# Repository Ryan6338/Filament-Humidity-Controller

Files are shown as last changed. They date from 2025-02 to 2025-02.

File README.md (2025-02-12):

# ESPHome Filament Humidity Controller (P/N 000001)
## Overview
This project is for an ESPHome-based 3D printer filament box. The purpose of the PCB is to automatically control a fan which will drive air through dessicant in a 3D printer filament drybox. Using ESPHome allows for easy configuration & automation customization through ESPHome and Home Assistant. It also allows for notifications to be configured when the dessicant has been depleted. The PCB is powered from a USB-C port requiring a 5V, 1A capable USB source. The USB port can be used for flashing the onboard ESP, although after ESPHome firmware has been installed, over the air updates can be used instead.

<p align="center">
  
</p>

## File Layout
### [KiCAD](KiCAD/)
The KiCAD folder contains the entire KiCAD project. This can be used to modify the board.
### [Manufacturing Documents](Manufacturing%20Documents/)
The manufacturing documents contains all output files of the KiCAD project. These files fully define the finished PCB. The main document is 000001.pdf. This file has notes defining the other files.
### [Calculations](Calculations/)
Calculations & design criteria can be found in the calculations folder. SMath (.sm) files are used to generate the output files in this folder (.pdf).
### [Simulations](Simulations/)
The simulations folder contains LTSpice simulations generated during the project.
## Board Architecture
A block diagram of the board architecture is pictured below. Each block in the diagram is described in this section.

Humidity Controller Block Diagram

### USB-C Connector
The board takes in power from the USB-C connector and runs it to both a 12V boost converter and 3.3V linear regulator. The CC pins are used by the upstream device to communicate how much power can be supplied.
### 12V Boost Converter
The 12V boost converter receives 5V (4.75-5.25V) from the USB-C connector & converts it into 12V for the fan. The boost converter is only active when the enable signal is triggered by the ESP32.
### 3.3V Linear Regulator
The 3.3V linear regulator receives 5V from the USB-C connector and regulates it to 3.3V for the humidity sensor & ESP32.
### Humidity Sensor
The humidity sensor receives 3.3V from the linear regulator & is an I2C slave device on the I2C bus connected to the ESP32.
### ESP32
The ESP32 runs ESPHome firmware with a driver to perform fan control with speed feedback & to receive humidity sensor data. Using the custom humidity sensor & fan drivers, the firmware for the ESP32 can be generated using a standard ESPHome yaml file. The ESP32 interfaces with an ESPHome server allowing for easy configuration of control parameters. Upon power on, the ESP32 reads the voltage of the CC pins to ensure adequate power is available from the USB supply prior to enabling the boost converter.
### Fan Connector
The fan connector is a standard 4-Pin computer fan connector which can be used with any 12V computer fan which has a maximum current draw of 200mA or less.
## TODO
1. Write custom ESPHome driver.
2. Create example yaml for ESPHome using custom driver.
3. Design PCB bracket, fan housing & dessicant holder.
## Future Improvements
To make this product consumer-ready, the following improvements should be considered:
1. Add fuse to 5V input.
2. Add ESD protection on USB & fan connectors.

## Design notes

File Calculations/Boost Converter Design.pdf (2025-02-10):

## Non-synchronous Boost Converter Calculations

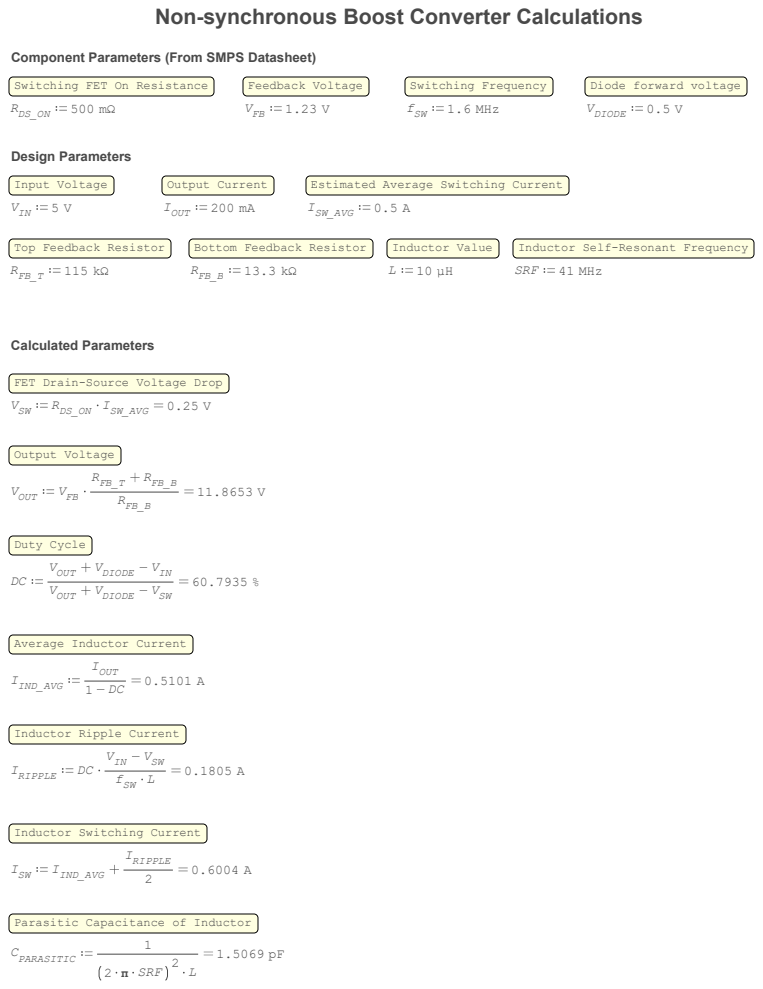
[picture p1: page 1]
Feedback Voltage; Switching Frequency; MHz1.6 SW; 0.5 V DIODE; Design Parameters; Input Voltage; Output Current; mA200 OUT; 0.5 A SW_AVG; Inductor Value; SRF; MHz41; Calculated Parameters; 0.25 V SW_AVG RDS_ON VSW; Output Voltage; RFB_B; RFB_B RFB_T VFB VOUT; IOUT; IIND_AVG; 0.1805 A LfSW; VSW VIN I; DC RIPPLE; 2 π SRF

Component Parameters (From SMPS Datasheet)

Switching FET On Resistance

Diode forward voltage

Estimated Average Switching Current

Top Feedback Resistor

Bottom Feedback Resistor

Inductor Self-Resonant Frequency

FET Drain-Source Voltage Drop

Duty Cycle
VIN VDIODE VOUT

VSW VDIODE VOUT

Average Inductor Current

Inductor Ripple Current

Inductor Switching Current
IRIPPLE IIND_AVG ISW

Parasitic Capacitance of Inductor
1 CPARASITIC

## Output Filter Design

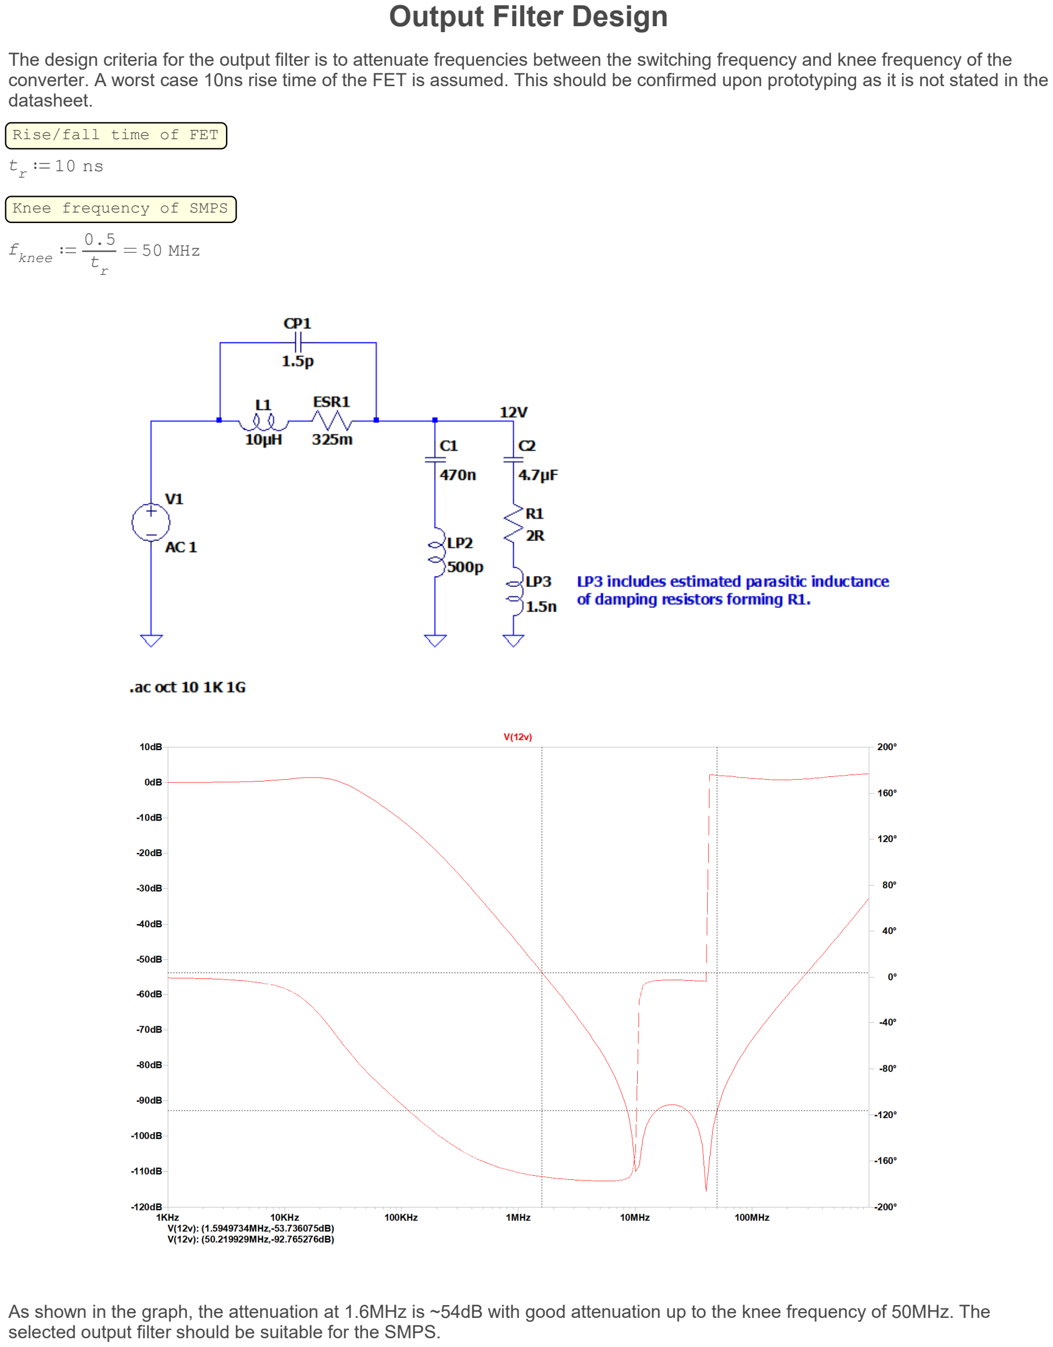
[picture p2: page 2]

The design criteria for the output filter is to attenuate frequencies between the switching frequency and knee frequency of the converter. A worst case 10ns rise time of the FET is assumed. This should be confirmed upon prototyping as it is not stated in the datasheet.

Rise/fall time of FET
t | ns10 r

Knee frequency of SMPS

MHz50
tr

0.5 fknee

As shown in the graph, the attenuation at 1.6MHz is ~54dB with good attenuation up to the knee frequency of 50MHz. The selected output filter should be suitable for the SMPS.

## Transient Analysis

A transient analysis was performed to check the circuit performs as expected. The fixed duty cycle calculated in the SMPS calcs. This simulation does not include the control loop of the SMPS. It is assumed to be stable as the loop compensation recommendations in the datasheet have been followed.

Parameters found by simulation:
Avg Inductor Current (L1): 570mA
Peak Inductor Current (L1): 650mA
Output Ripple Voltage: 250μA
Avg Power of ESR2: 2.3mW

The inductor current was found to be slightly higher during the simulation, this is mostly due to the inclusion of ESR in the simulated inductor. Otherwise, the calculated duty cycle matched the simulation results, a 60.79% duty cycle resulted in an output voltage (BST_12V) of 11.86V. As shown in the graph, the output filter is effective at attenuating the switching noise.

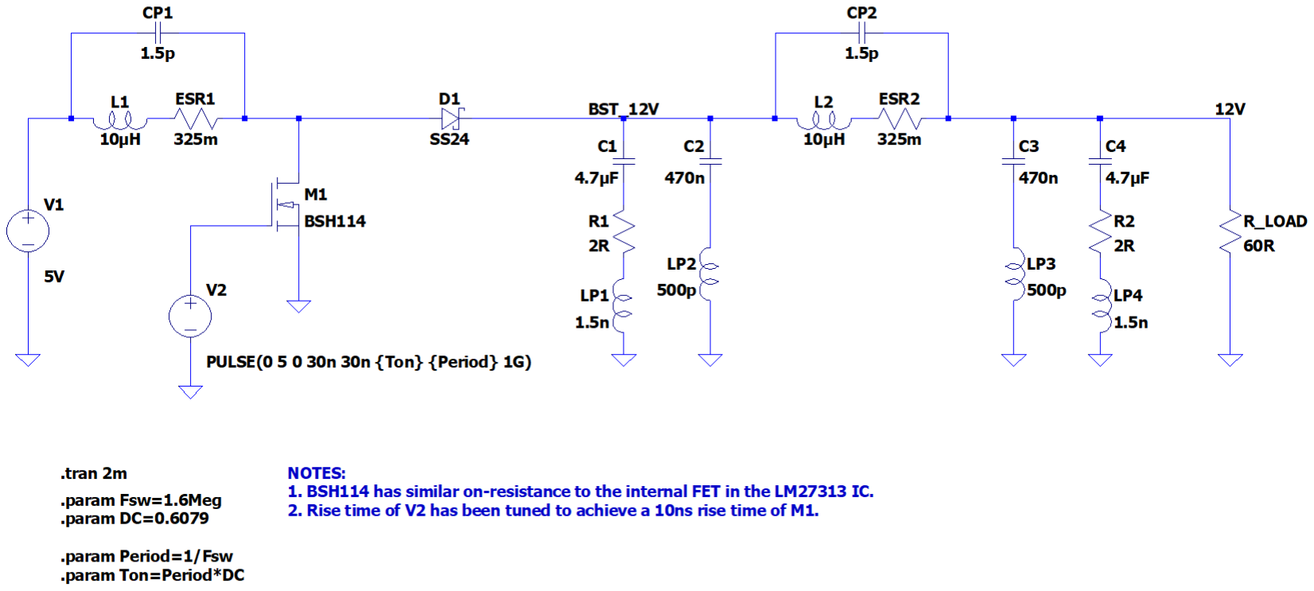
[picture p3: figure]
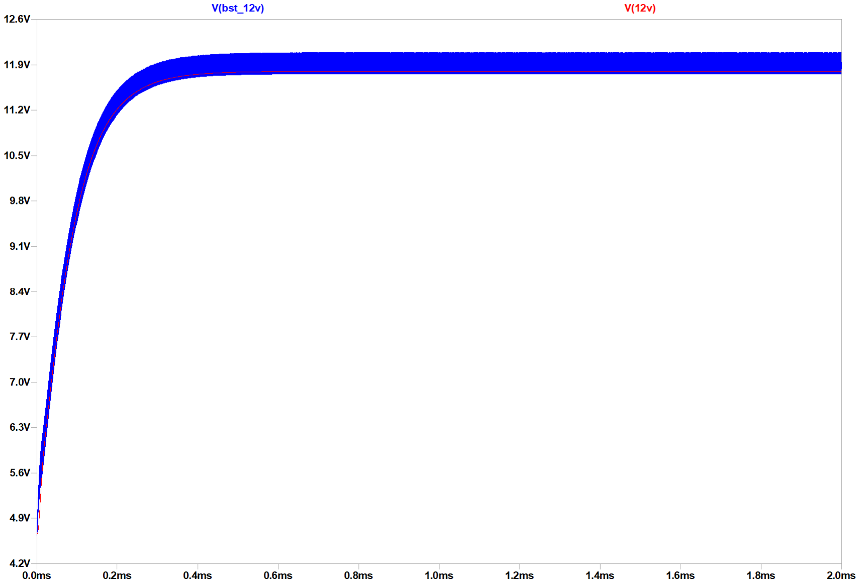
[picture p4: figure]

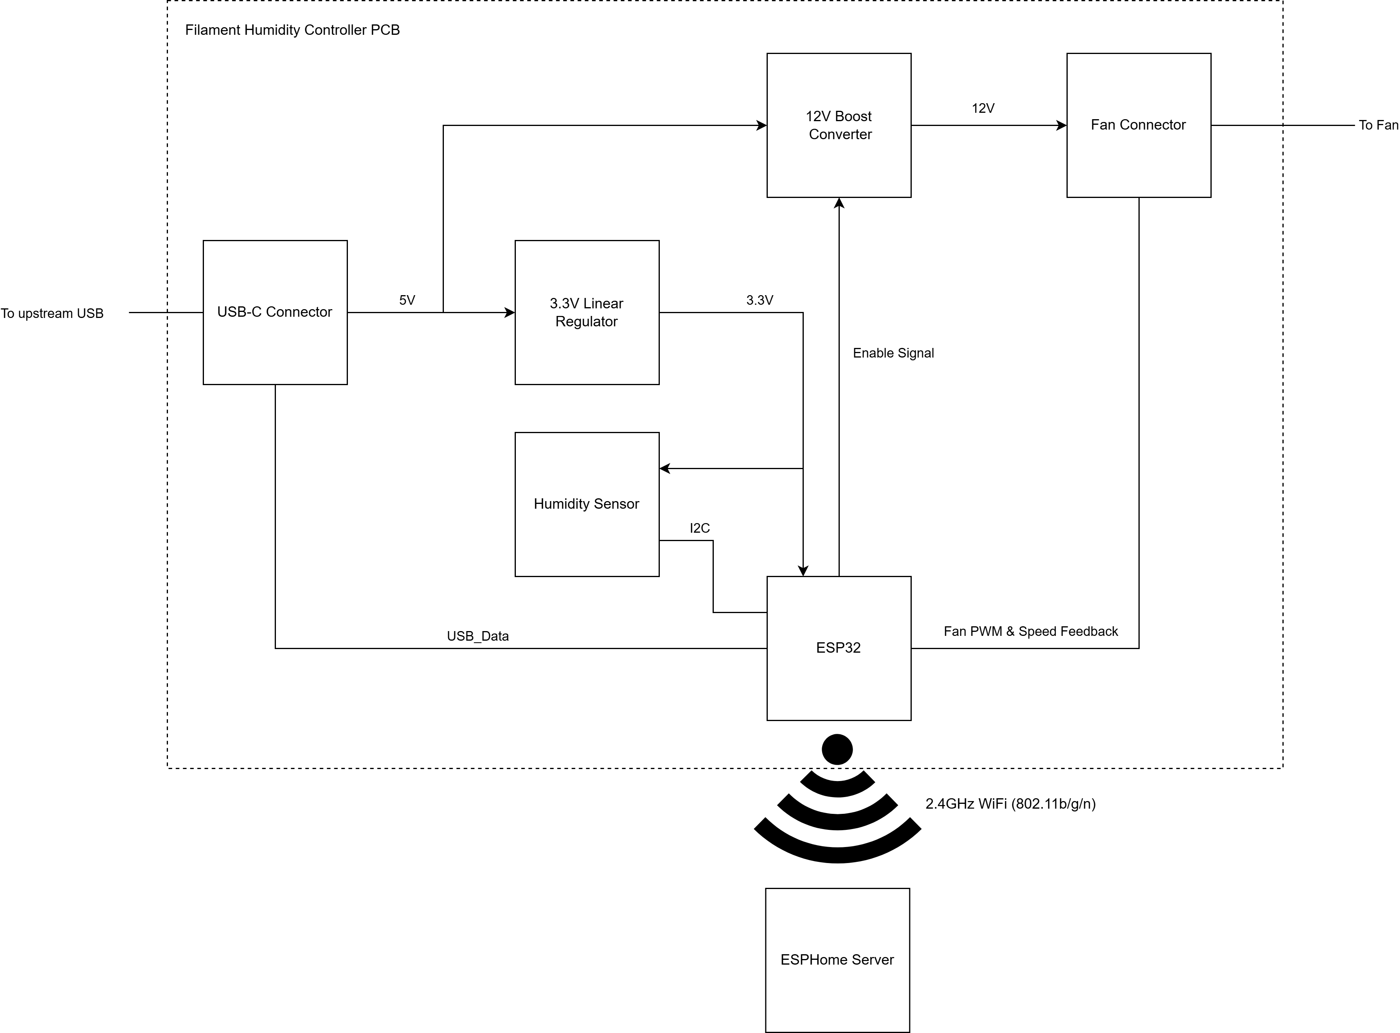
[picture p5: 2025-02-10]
Humidity Controller Block Diagram.png

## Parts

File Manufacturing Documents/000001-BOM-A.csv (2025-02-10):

Reference | Value | Qty | MF | MPN | Description | JLCPCB Part #
C1,C2,C6 | 4.7uF | 3 | FH (Guangdong Fenghua Advanced Tech) | 1206B475K500NT | MLCC 4.7uF X7R 50V 1206 | C29823
C3,C4,C5 | 470nF | 3 | Samsung Electro-Mechanics | CL10B474KA8NNNC | MLCC 470nF 25V X7R 0603 | C1623
C7 | 22uF | 1 | Samsung Electro-Mechanics | CL10A226MQ8NRNC | MLCC 4.7uF X5R 6.3V 0603 | C59461
C8 | 220pF | 1 | FH (Guangdong Fenghua Advanced Tech) | 0402B221K500NT | MLCC 220pF X7R 50V 0402 | C1530
D1 | SS14 | 1 | SS14 | MDD(Microdiode Semiconductor) | 40V 1A Schottky Diode, SMA | C2480
J1 | Conn_01x04_Pin | 1 | Molex | 47053-1000 | KK 254 Vertical Header, with Friction Lock, 4 Circuits | C240840
J3 | 918-418K2023S40001 | 1 | Jing | 918-418K2023S40001 | USB 2.0-only 16P Type-C Receptacle connector | C167321
L1,L2 | 10uH | 2 | Sunlord | SWPA3015S100MT | Inductor 10uH 1.2A Isat | C45403
R1,R6,R7,R8,R11 | 1R | 5 | UNI-ROYAL(Uniroyal Elec) | 0603WAF100KT5E | Resistor 1R 0603 | C22936
R2 | 115K | 1 | UNI-ROYAL(Uniroyal Elec) | 0402WGF1153TCE | Resistor 115K 0402 | C25747
R3,R4 | 4.7K | 2 | UNI-ROYAL(Uniroyal Elec) | 0402WGF4701TCE | Resistor 4.7K 0402 | C25900
R5,R12 | 13.3K | 2 | UNI-ROYAL(Uniroyal Elec) | 0402WGF1332TCE | Resistor 13.3K 0402 | C122547
R9,R10 | 5.1K | 2 | UNI-ROYAL(Uniroyal Elec) | 0402WGF5101TCE | Resistor 5.1K 0402 | C25905
U1 | ESP32-S3-MINI-1 | 1 | Espressif Systems | ESP32-S3-MINI-1-N8 | RF Module, ESP32-S3 SoC, Wi-Fi 802.11b/g/n, Bluetooth, BLE, 32-bit, 3.3V, SMD, onboard antenna | C2913206
U3 | HDC3022DEJR | 1 | Texas Instruments | HDC3022DEJR | Board Mount Humidity Sensors 0.5% RH digital humidity sensor, 0.19% long-term drift, 400 nA, 4-sec response time, NIST traceable | C7472806
U4 | LM27313XMF_NOPB | 1 | Texas Instruments | LM27313XMF/NOPB | 1.6 MHz Boost Converter With 30V Internal FET Switch in SOT-23 | C32355
U5 | AMS1117-3.3 | 1 | Advanced Monolithic Systems | AMS1117-3.3 | 1A Low Dropout regulator, positive, 3.3V fixed output, SOT-223 | C6186

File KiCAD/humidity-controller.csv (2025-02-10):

Id | Designator | Footprint | Quantity | Designation | Supplier and ref
1 | U4 | SOT95P280X145-5N | 1 | LM27313XMF_NOPB
2 | U3 | SON50P250X250X80-9N-D | 1 | HDC3020DEFR
3 | R12,R5 | R_0402_1005Metric | 2 | 13.3K
4 | C8 | C_0402_1005Metric | 1 | 220pF
5 | R11,R7,R6,R8,R1 | C_0603_1608Metric | 5 | 1R
6 | C7 | C_0603_1608Metric | 1 | 22uF
7 | J3 | USB_C_Receptacle_GCT_USB4105-xx-A_16P_TopMnt_Horizontal | 1 | USB_C_Receptacle_USB2.0_14P
8 | U2 | TO-252-3_TabPin2 | 1 | AMS1117CD-3.3
9 | R10,R9 | R_0402_1005Metric | 2 | 5.1K
10 | R4,R3 | R_0402_1005Metric | 2 | 4.7K
11 | D1 | D_SMA | 1 | SS14
12 | C6,C1,C2 | C_1206_3216Metric | 3 | 4.7uF
13 | J1 | 470531000 | 1 | Conn_01x04_Pin
14 | L2,L1 | L_Sunlord_SWPA3015S | 2 | 10uH
15 | R2 | R_0402_1005Metric | 1 | 117K
16 | C5,C4,C3 | C_0603_1608Metric | 3 | 470nF
17 | U1 | ESP32-S2-MINI-1 | 1 | ESP32-S3-MINI-1

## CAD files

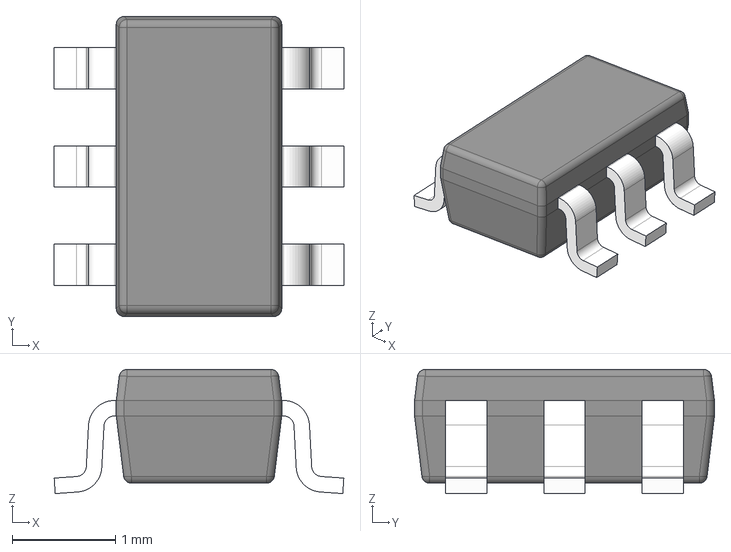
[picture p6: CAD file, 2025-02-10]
KiCAD/3D Models/SOT-23-6.stp
2.80 x 2.90 x 1.20 mm
BODY-SOT
LEAD-SOT x 6

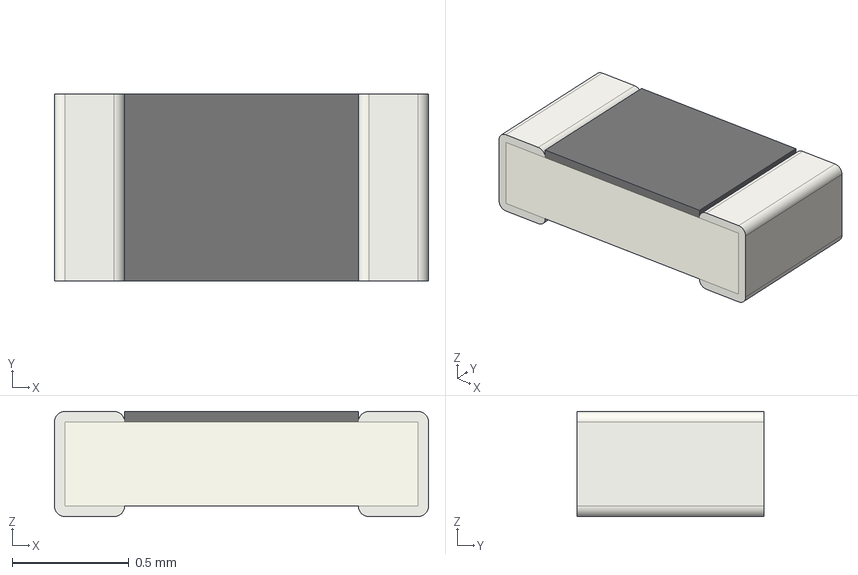
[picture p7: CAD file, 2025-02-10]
KiCAD/3D Models/0603 Fuse.step
1.60 x 0.8 x 0.45 mm

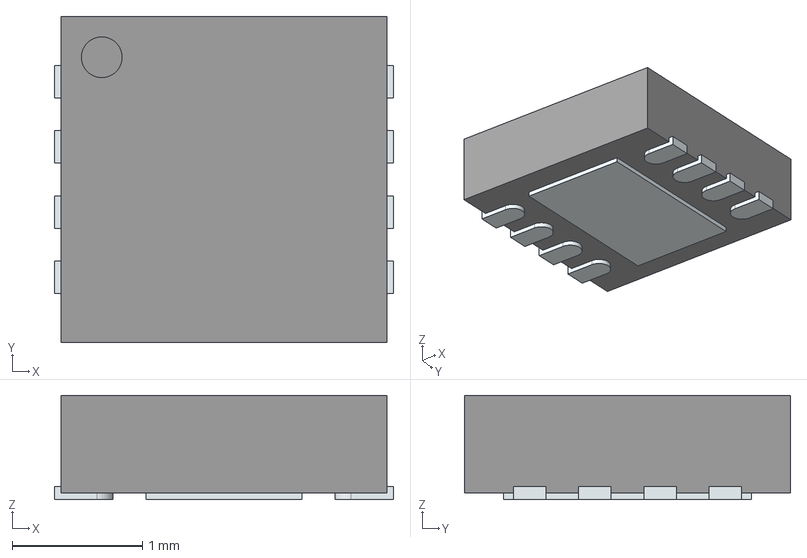
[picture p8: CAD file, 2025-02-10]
KiCAD/3D Models/HDC3020DEFR.stp
2.60 x 2.50 x 0.8 mm
ThermalPin
PinsArrayLR

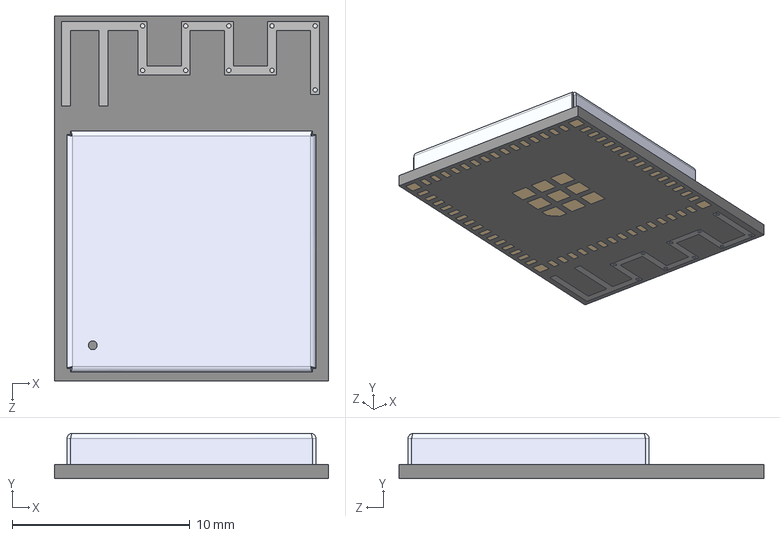
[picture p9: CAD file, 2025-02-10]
KiCAD/3D Models/ESP32-S3-MINI-1-N8.stp
15.4 x 2.55 x 20.5 mm

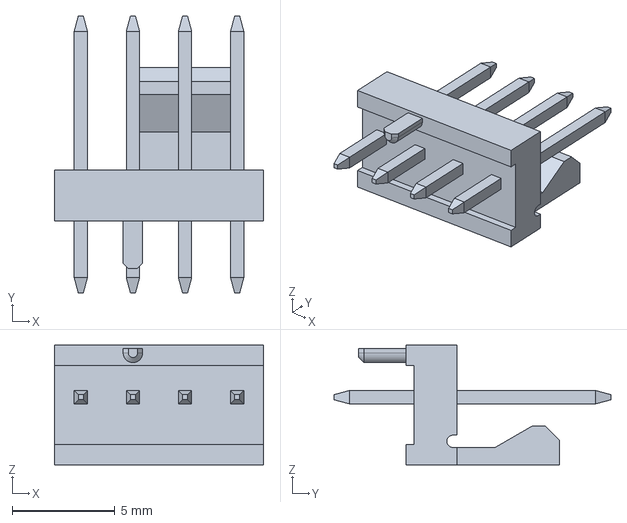
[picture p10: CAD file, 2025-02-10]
KiCAD/3D Models/47053-1000.stp
10.2 x 13.5 x 5.84 mm

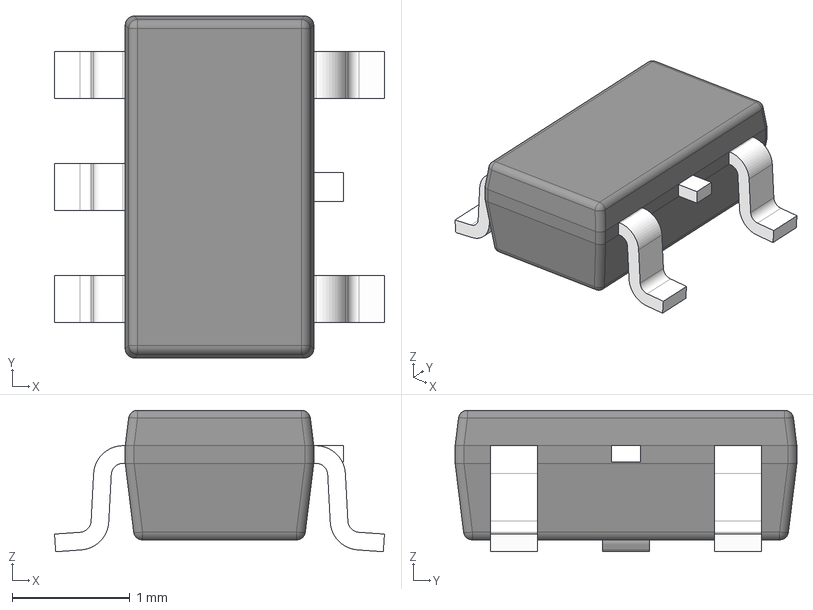
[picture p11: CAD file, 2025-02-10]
KiCAD/3D Models/LM27313XMF_NOPB.stp
2.80 x 2.90 x 1.20 mm
BODY-SOT
LEAD-SOT x 5
LEAD-DUMMY

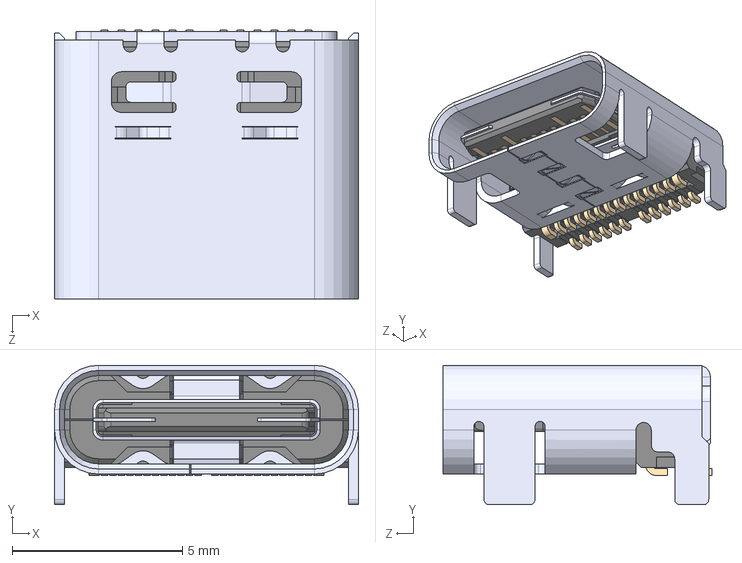
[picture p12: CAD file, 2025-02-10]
KiCAD/3D Models/1054500101.step
8.94 x 4.10 x 7.90 mm

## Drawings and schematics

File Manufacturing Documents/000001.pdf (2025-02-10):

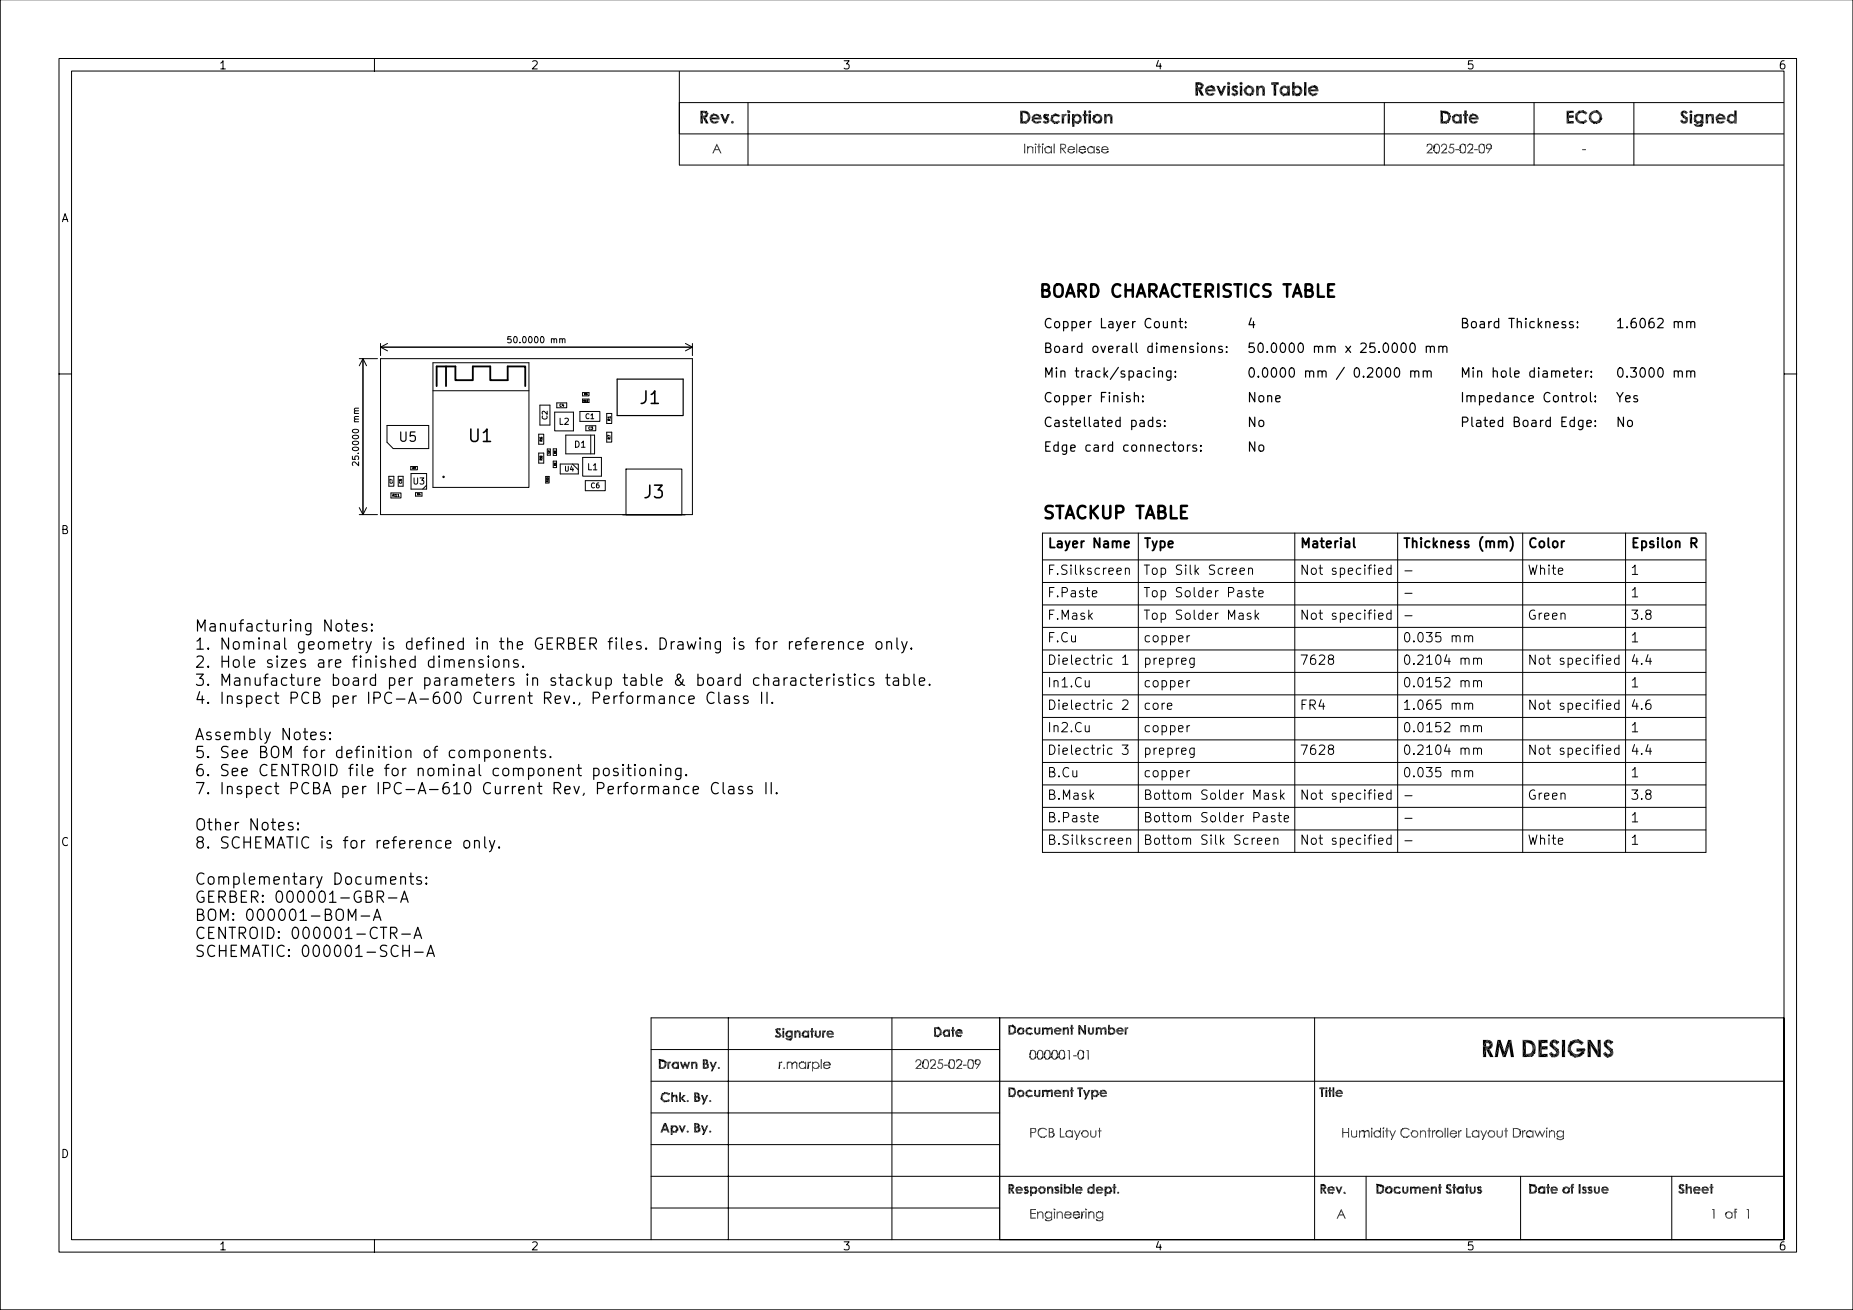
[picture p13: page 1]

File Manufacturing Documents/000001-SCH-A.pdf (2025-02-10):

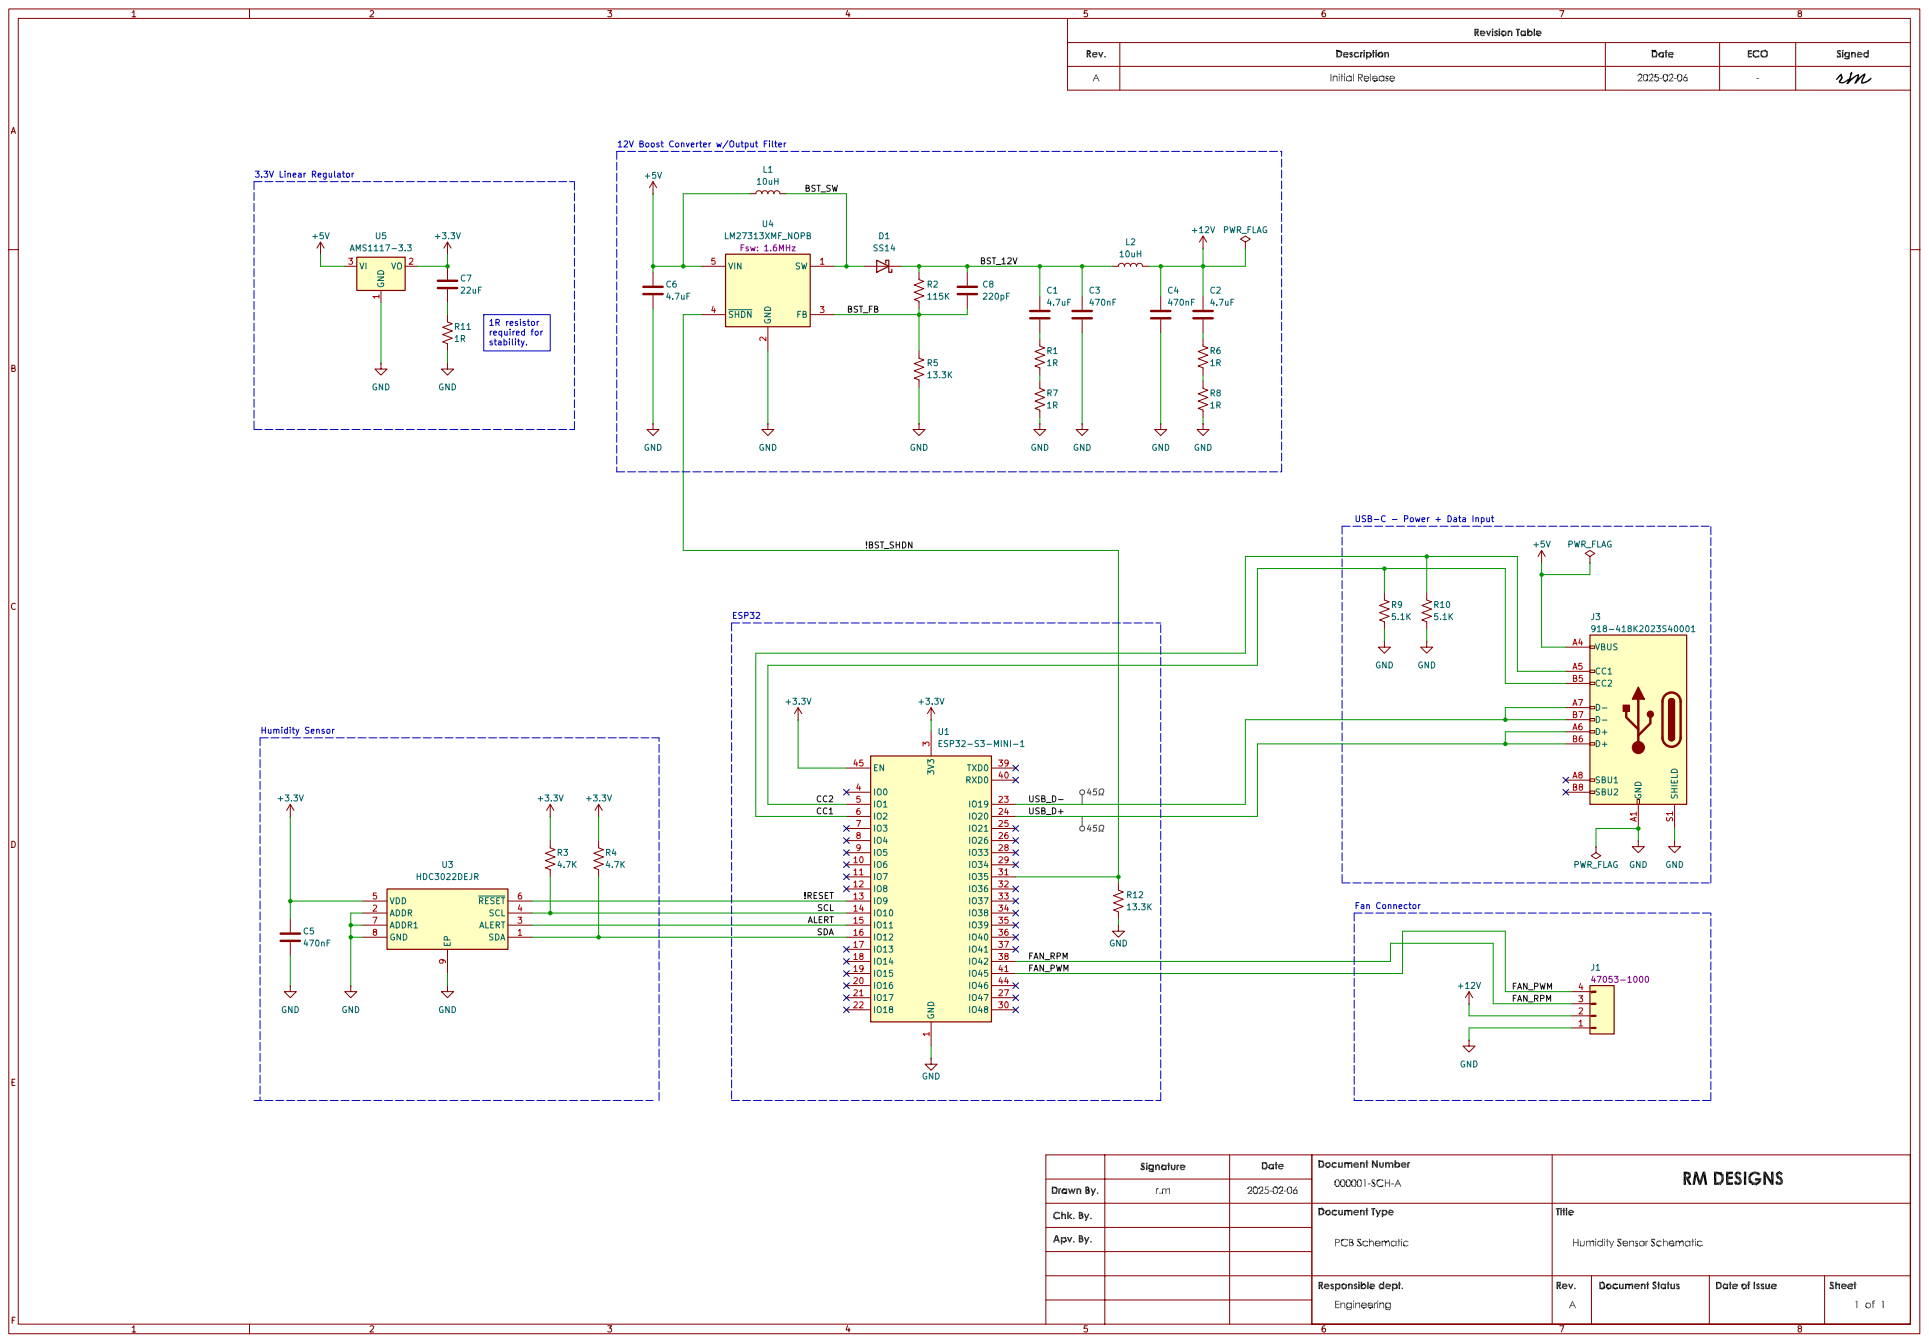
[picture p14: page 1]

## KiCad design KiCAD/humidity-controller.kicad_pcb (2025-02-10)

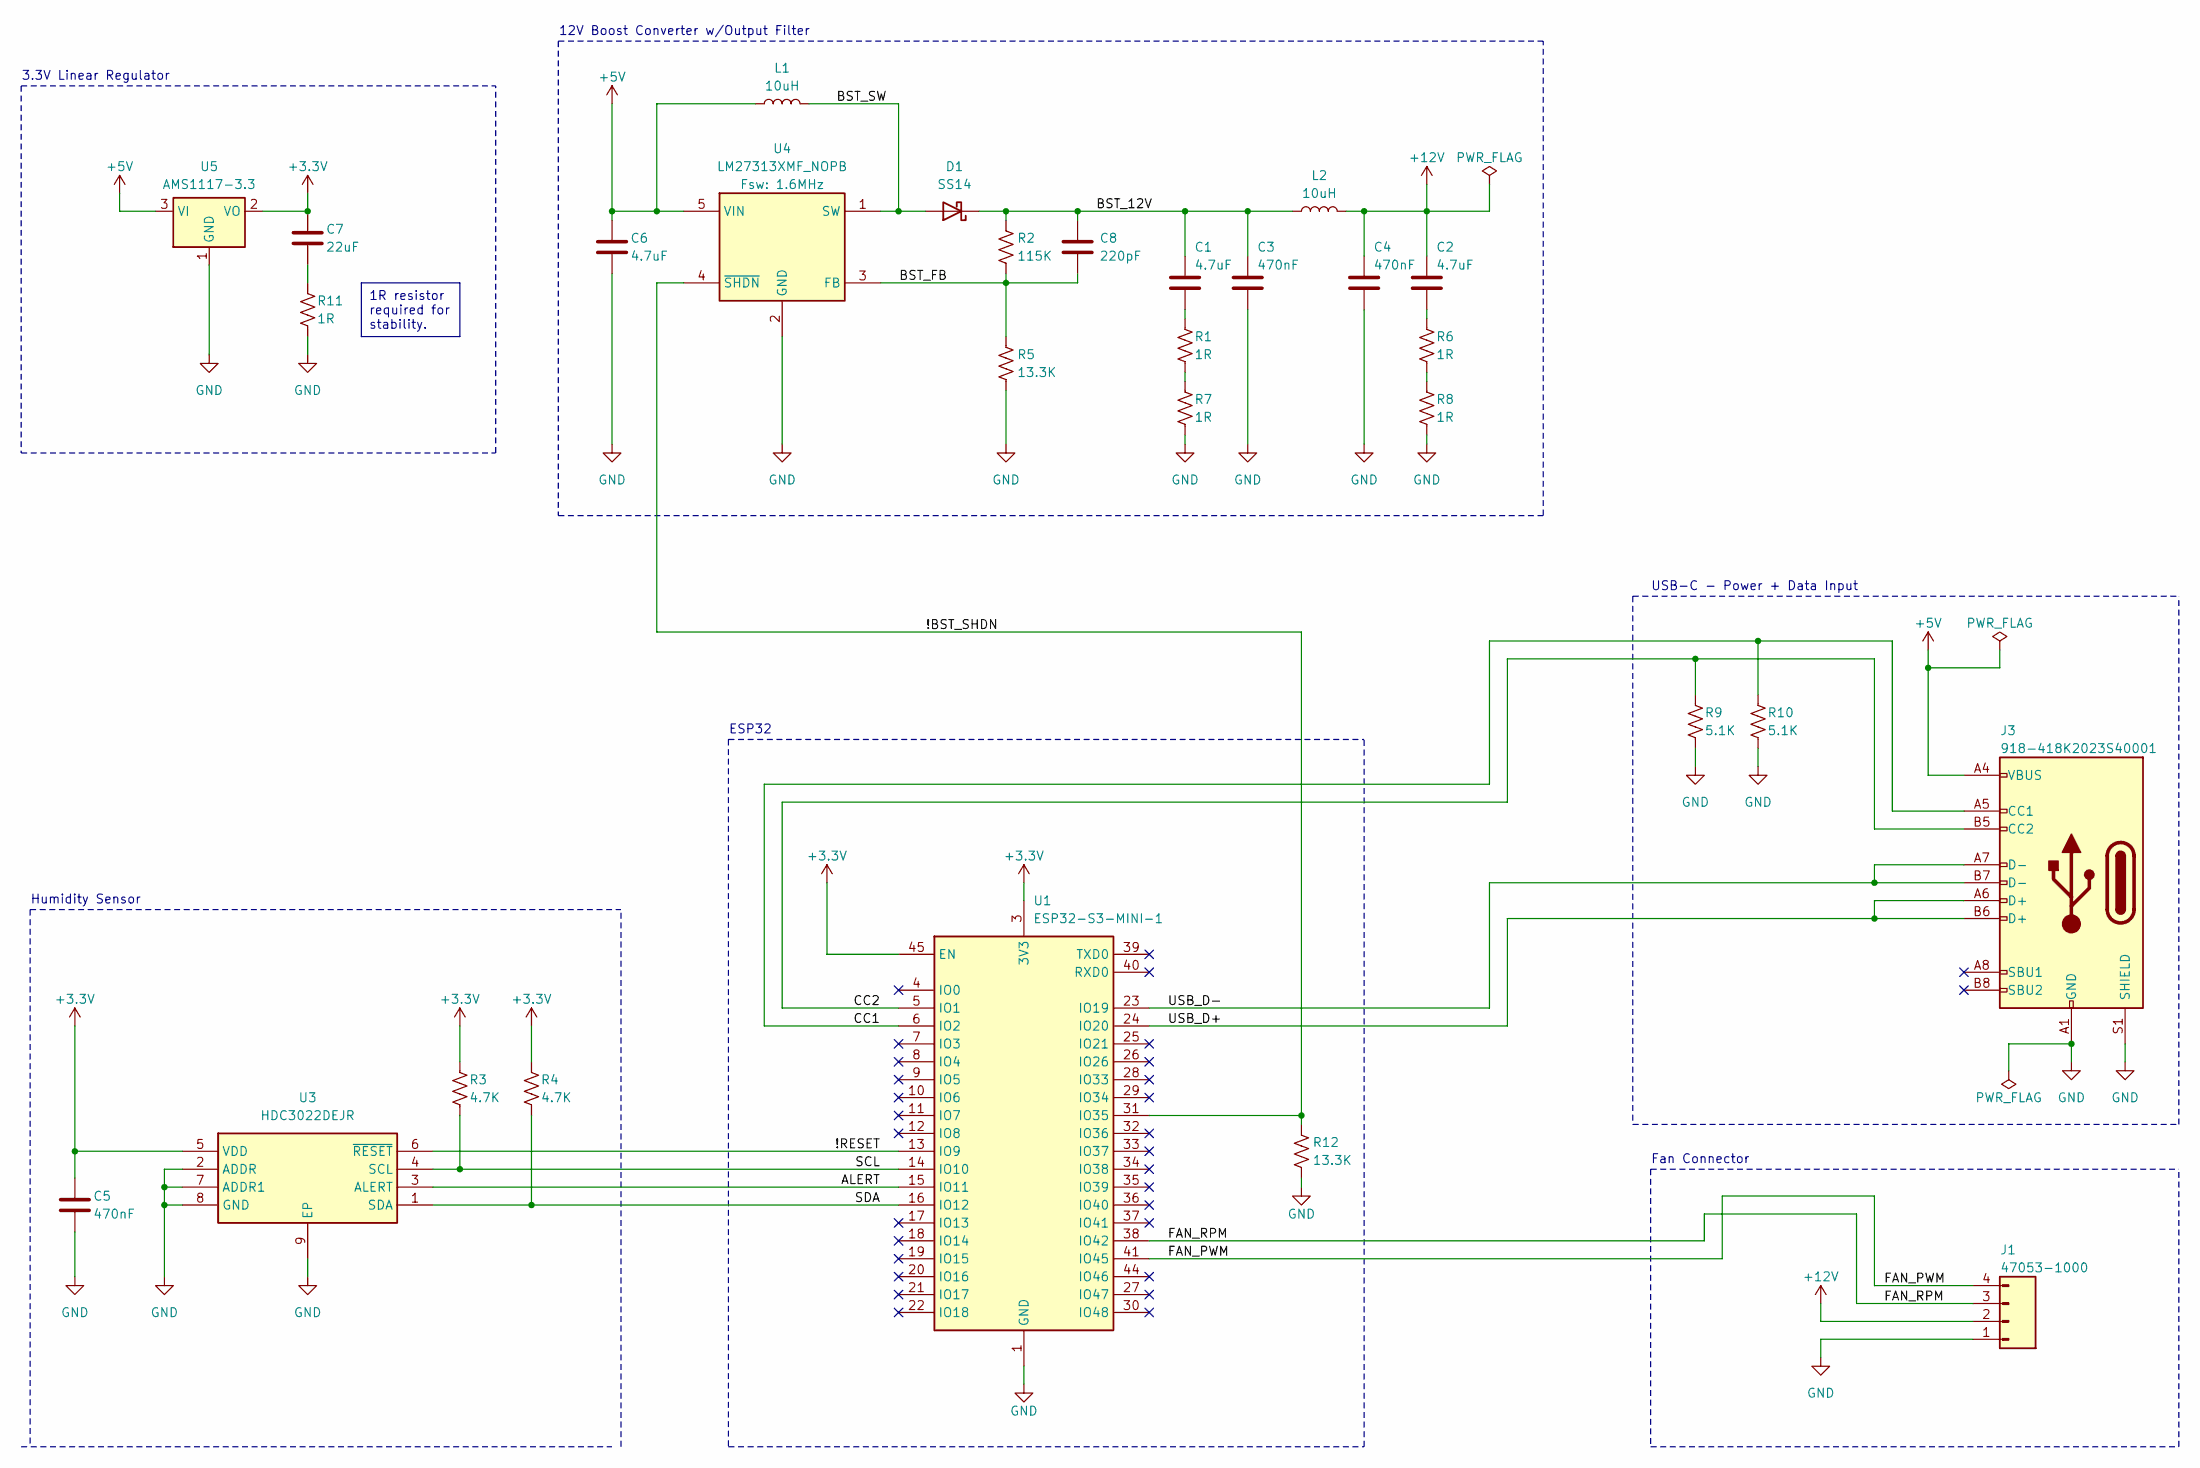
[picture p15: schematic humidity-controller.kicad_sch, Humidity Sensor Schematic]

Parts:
C1, C2, C6: 4.7uF; C_1206_3216Metric; MPN 1206B475K500NT; JLCPCB Part # C29823
C3, C4, C5: 470nF; C_0603_1608Metric; MPN CL10B474KA8NNNC; JLCPCB Part # C1623
C7: 22uF; C_0603_1608Metric; MPN CL10A226MQ8NRNC; JLCPCB Part # C59461
C8: 220pF; C_0402_1005Metric; MPN 0402B221K500NT; JLCPCB Part # C1530
D1: SS14; D_SMA; MPN MDD(Microdiode Semiconductor); JLCPCB Part # C2480
J1: Conn_01x04_Pin; 470531000; MPN 47053-1000; JLCPCB Part # C240840
J3: 918-418K2023S40001; USB_C_Receptacle_GCT_USB4105-xx-A_16P_TopMnt_Horizontal; MPN 918-418K2023S40001; JLCPCB Part # C167321
L1, L2: 10uH; L_Sunlord_SWPA3015S; MPN SWPA3015S100MT; JLCPCB Part # C45403
R1, R6, R7, R8, R11: 1R; C_0603_1608Metric; MPN 0603WAF100KT5E; JLCPCB Part # C22936
R2: 115K; R_0402_1005Metric; MPN 0402WGF1153TCE; JLCPCB Part # C25747
R3, R4: 4.7K; R_0402_1005Metric; MPN 0402WGF4701TCE; JLCPCB Part # C25900
R5, R12: 13.3K; R_0402_1005Metric; MPN 0402WGF1332TCE; JLCPCB Part # C122547
R9, R10: 5.1K; R_0402_1005Metric; MPN 0402WGF5101TCE; JLCPCB Part # C25905
U1: ESP32-S3-MINI-1; ESP32-S2-MINI-1; MPN ESP32-S3-MINI-1-N8; JLCPCB Part # C2913206
U3: HDC3022DEJR; SON50P250X250X80-9N-D; MPN HDC3022DEJR; JLCPCB Part # C7472806
U4: LM27313XMF_NOPB; SOT95P280X145-5N; MPN LM27313XMF/NOPB; JLCPCB Part # C32355
U5: AMS1117-3.3; SOT-223-3_TabPin2; MPN AMS1117-3.3; JLCPCB Part # C6186

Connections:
+3.3V: C5.1, C7.1, R3.1, R4.1, U1.3 (3V3), U1.45 (EN), U3.5 (VDD), U5.2 (VO)
+5V: C6.1, J3.A4 (VBUS), J3.A9 (VBUS), J3.B4 (VBUS), J3.B9 (VBUS), L1.1, U4.5 (VIN), U5.3 (VI)
+12V: C2.1, C4.1, J1.2, L2.2
/!BST_SHDN: R12.1, U1.31 (IO35), U4.4 (~SHDN)
/!RESET: U1.13 (IO9), U3.6 (~RESET)
/ALERT: U1.15 (IO11), U3.3 (ALERT)
/BST_12V: C1.1, C3.1, C8.1, D1.1 (K), L2.1, R2.1
/BST_FB: C8.2, R2.2, R5.1, U4.3 (FB)
/BST_SW: D1.2 (A), L1.2, U4.1 (SW)
/CC1: J3.A5 (CC1), R10.1, U1.6 (IO2)
/CC2: J3.B5 (CC2), R9.1, U1.5 (IO1)
/FAN_PWM: J1.4, U1.41 (IO45)
/FAN_RPM: J1.3, U1.38 (IO42)
/SCL: R3.2, U1.14 (IO10), U3.4 (SCL)
/SDA: R4.2, U1.16 (IO12), U3.1 (SDA)
/USB_D+: J3.A6 (D+), J3.B6 (D+), U1.24 (IO20)
/USB_D-: J3.A7 (D-), J3.B7 (D-), U1.23 (IO19)
GND: C3.2, C4.2, C5.2, C6.2, J1.1, J3.A1 (GND), J3.A12 (GND), J3.B1 (GND), J3.B12 (GND), J3.S1 (SHIELD), R5.2, R7.1, R8.1, R9.2, R10.2, R11.1, R12.2, U1.1 (GND), U1.2 (GND), U1.42 (GND), U1.43 (GND), U1.46 (GND), U1.47 (GND), U1.48 (GND), U1.49 (GND), U1.50 (GND), U1.51 (GND), U1.52 (GND), U1.53 (GND), U1.54 (GND), U1.55 (GND), U1.56 (GND), U1.57 (GND), U1.58 (GND), U1.59 (GND), U1.60 (GND), U1.61 (GND), U1.62 (GND), U1.63 (GND), U1.64 (GND), U1.65 (GND), U3.2 (ADDR), U3.7 (ADDR1), U3.8 (GND), U3.9 (EP), U4.2 (GND), U5.1 (GND)
unnamed: C1.2, R1.2
unnamed: C2.2, R6.2
unnamed: C7.2, R11.2
unnamed: R1.1, R7.2
unnamed: R6.1, R8.2

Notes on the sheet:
1R resistor required for stability.
Humidity Sensor
3.3V Linear Regulator
USB-C - Power + Data Input
ESP32
Fan Connector
12V Boost Converter w/Output Filter

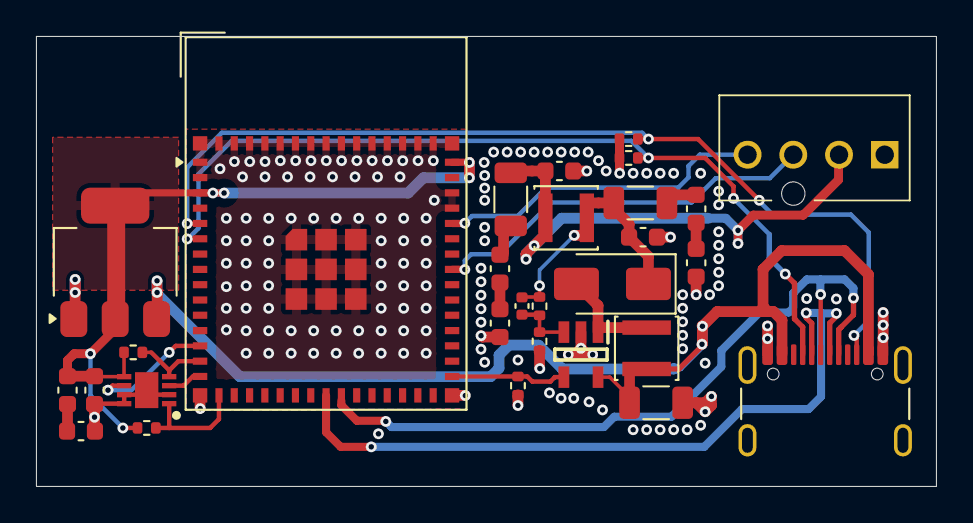
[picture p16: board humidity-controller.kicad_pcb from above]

Board: 4 copper layers, 50.0 x 25.0 mm, 29 parts (0 on the bottom side), 23 nets.

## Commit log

2025-02-10 Initial Release
    [000001-BOM-A.csv, 000001-CTR-A.csv, 0603 Fuse.step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]
2025-02-10 Update README.md
    Added rendering of PCB
2025-02-10 Updated main drawing to improve component text readability
    [humidity-controller.kicad_pcb]
2025-02-12 Update README.md
    Added picture of actual PCB to readme.
2025-02-12 Added esphome configuration yaml enabling fan control. Humidity sensor reading needs to have a custom component developed.
    [filament-humidity-controller.yaml]

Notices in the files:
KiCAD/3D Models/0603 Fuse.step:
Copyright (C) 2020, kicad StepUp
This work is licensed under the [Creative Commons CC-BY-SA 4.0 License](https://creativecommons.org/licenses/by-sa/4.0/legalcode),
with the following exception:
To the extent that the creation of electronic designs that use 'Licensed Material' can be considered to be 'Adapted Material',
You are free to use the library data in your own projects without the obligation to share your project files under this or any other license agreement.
